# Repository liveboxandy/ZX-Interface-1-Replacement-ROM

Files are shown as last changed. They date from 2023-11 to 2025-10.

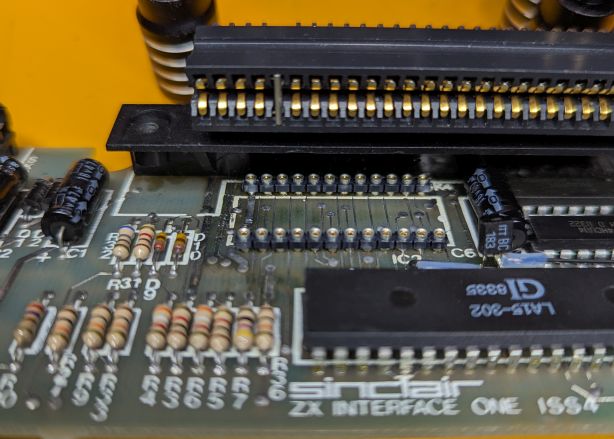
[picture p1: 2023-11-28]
Pictures/IF1 Sockets.jpg

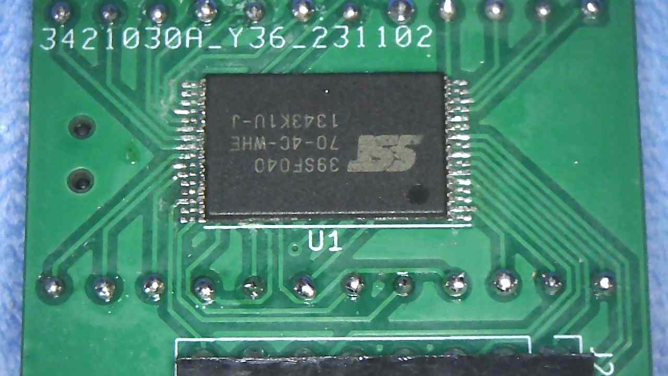
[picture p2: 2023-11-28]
Pictures/IF1 ROM SF040.jpg

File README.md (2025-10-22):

# ZX-Interface-1-Replacement-ROM
Replacement ROM for the ZX Interface 1

The original ROM for the ZX Interface 1 is a mask programmed device that is now obsolete. This work is based on an idea by Retroleum and others in using a flash device on a PCB in order to remap the pins to suit the original 24 pin device layout. When using the suggested Samtec pins there is just enough room in the Interface 1 to allow the use of Samtec sockets so the ROM can be removed if required. I have not found any other pins that are short enough to allow the use of a socket in the Interface 1. 

This PCB will support SST39SF010, SST39SF020 and SST39SF040 devices and will allow up to a maximum of 32 different ROM images to be used.

The orignal ROM is an 8K device but if address A13 is taken from the ROM and connected to A13 on the expansion BUS then the 16K ROM image by Ian Collier can be used. See picture for location of address A13 on the edge connector of the ZX Interface 1.

This has been updated to Kicad 9 and requires an adaptor board to remap the pins when programming.

The adapter board is available under ZX-Interface-1-Replacement-ROM-Programming-Adapter.

Comments - Good Bad or indifferent on https://www.facebook.com/groups/zxspa/

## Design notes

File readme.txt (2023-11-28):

Address Lines Avalable

Addr Hex  Dec  Max
A18 40000 256K 512K SST39SF040 Pulled Hi in Operation
A17 20000 128K 256K SST39SF020 Pulled Hi in Operation
A16 10000  64K 128K SST39SF010 Switched Hi/Lo by switch on my board.Pulled Lo by short to Ground on Retroleum.
A15  8000  32K  64K Switched Hi/Lo by switch on Retroleum.
A14  4000  16K  32K Pulled Hi in Operation
A13  2000   8K  16K Pulled Hi in Operation. Allows 16K Operation with wire add.
A12  1000   4K   8K
A11   800   2K   4K
A10   400   1K   2K 
A9    200  512   1K
A8    100  256  512
A7     80  128  256
6      40   64  128
5      20   32   64
4      10   16   32
3       8    8   16
2       4    4    8
1       2    2    4
0       1    1    2

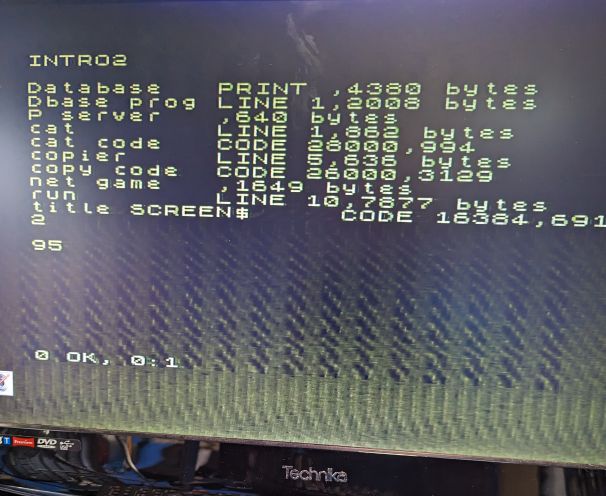
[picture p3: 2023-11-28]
Pictures/IMC ROM CAT.jpg

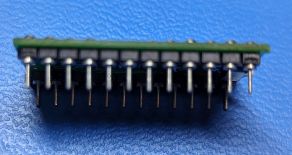
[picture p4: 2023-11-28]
Pictures/New ROM Pins.jpg

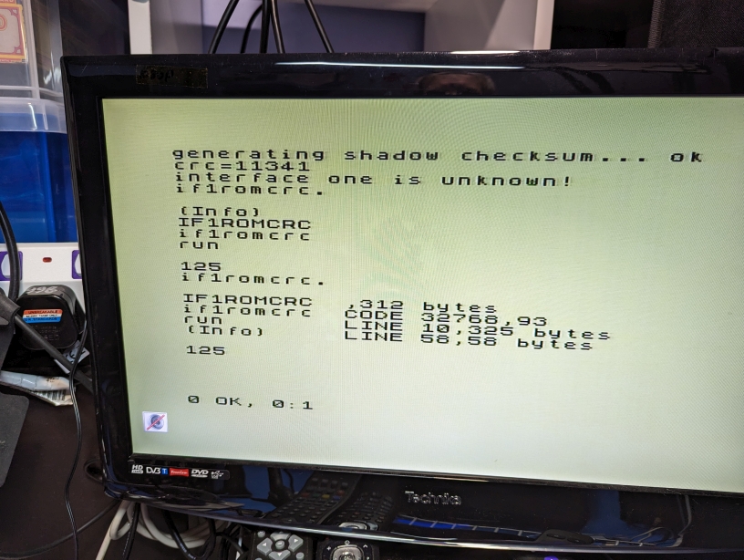
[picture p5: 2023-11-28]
Pictures/IMC Checksum & CAT.jpg

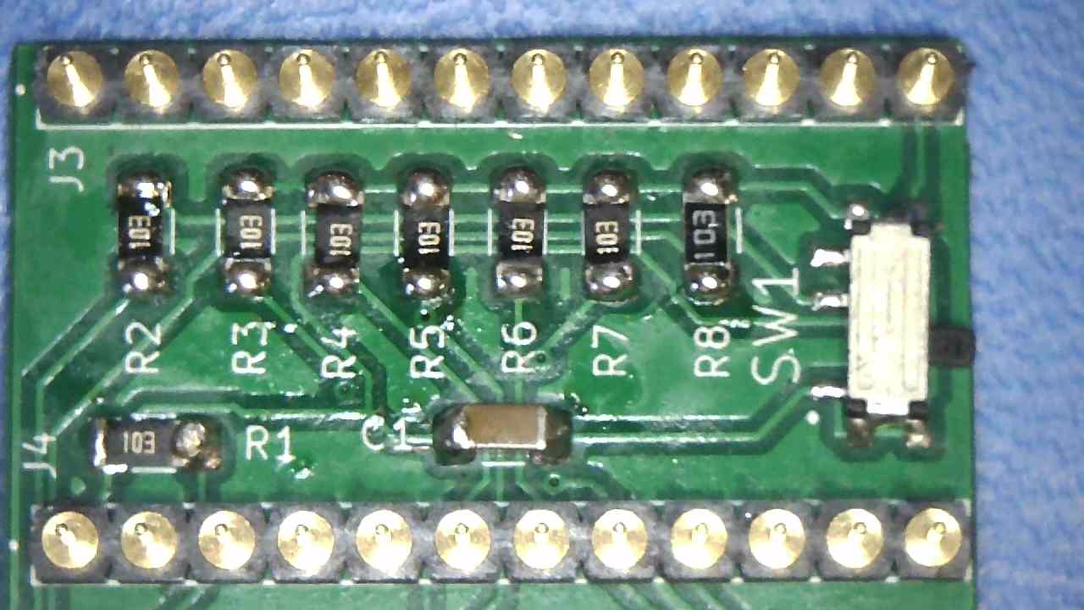
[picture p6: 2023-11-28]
Pictures/ROM Bottom Side.jpg

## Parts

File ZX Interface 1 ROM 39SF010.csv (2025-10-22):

Reference | Qty | Value | DNP | Exclude from BOM | Exclude from Board | Footprint | Datasheet
C1 | 1 | 100nF |  |  |  | Mod:C_1206_3216Metric_Pad1.33x1.80mm_HandSolder | ~
J1 | 1 | Conn_01x09_Pin |  |  |  | Switch:PinSocket_1x09_P2.54mm_HorizontalR | ~
J3,J4 | 2 | BBL-112-G-E |  |  |  | Mod:Pin-Pin Header 2.54mm Round Samtec BBL-112-G-E
R1,R2,R3,R4,R5,R6,R7,R8 | 8 | 10K |  |  |  | Mod:R_1206_3216Metric_Pad1.30x1.75mm_HandSolder | ~
SW1 | 1 | SW_SPDT |  |  |  | Mod:SW_PCM12SMTR | PCM12SMTR
U1 | 1 | SST39SF040A TSOP |  |  |  | Mod:TSOP-I-32_12.4x8mm_P0.5mm

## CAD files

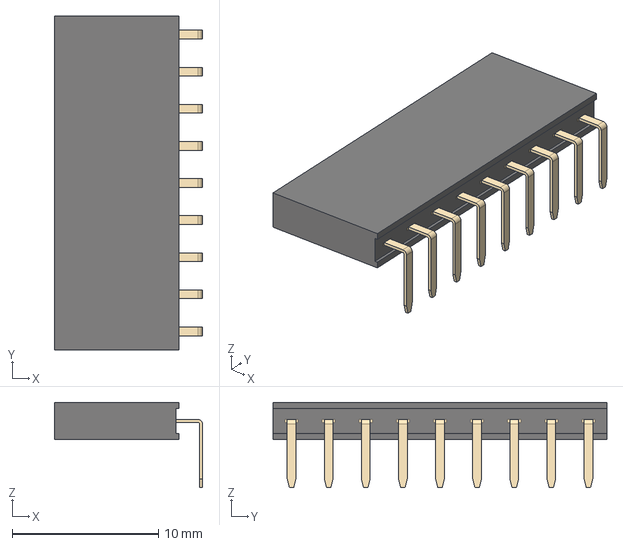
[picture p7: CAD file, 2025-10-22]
STEP/PinSocket_1x09_P2.54mm_Horizontal.step
10.1 x 22.9 x 5.84 mm

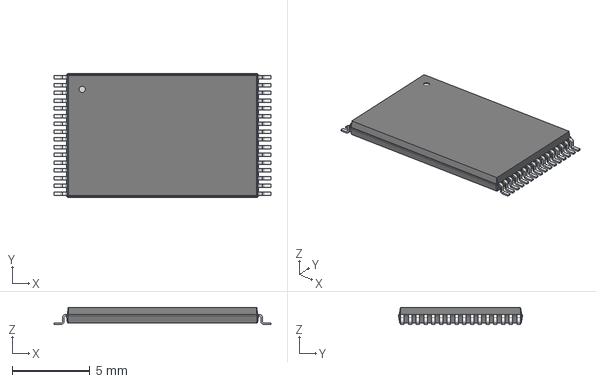
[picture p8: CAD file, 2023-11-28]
STEP/TSOP-I-32_12.4x8mm_P0.5mm.step
14.0 x 8.00 x 1.10 mm

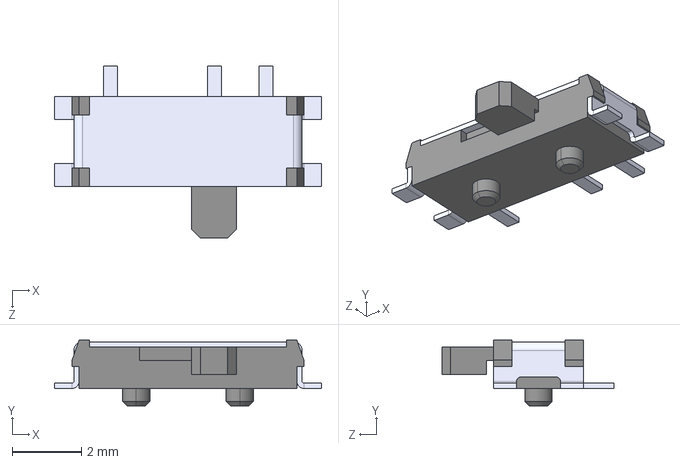
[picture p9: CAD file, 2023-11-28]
STEP/SW_PCM12SMTR.step
7.72 x 1.91 x 4.98 mm

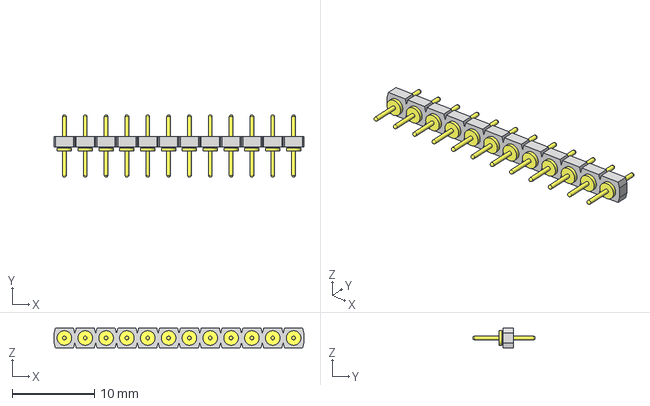
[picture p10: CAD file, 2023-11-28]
STEP/Pin-Pin Header 2.54mm Round Samtec BBL-112-G-E.stp
30.5 x 7.62 x 2.44 mm
BBL-112-G-E_pins x 12
BBL-112-G-E_socket

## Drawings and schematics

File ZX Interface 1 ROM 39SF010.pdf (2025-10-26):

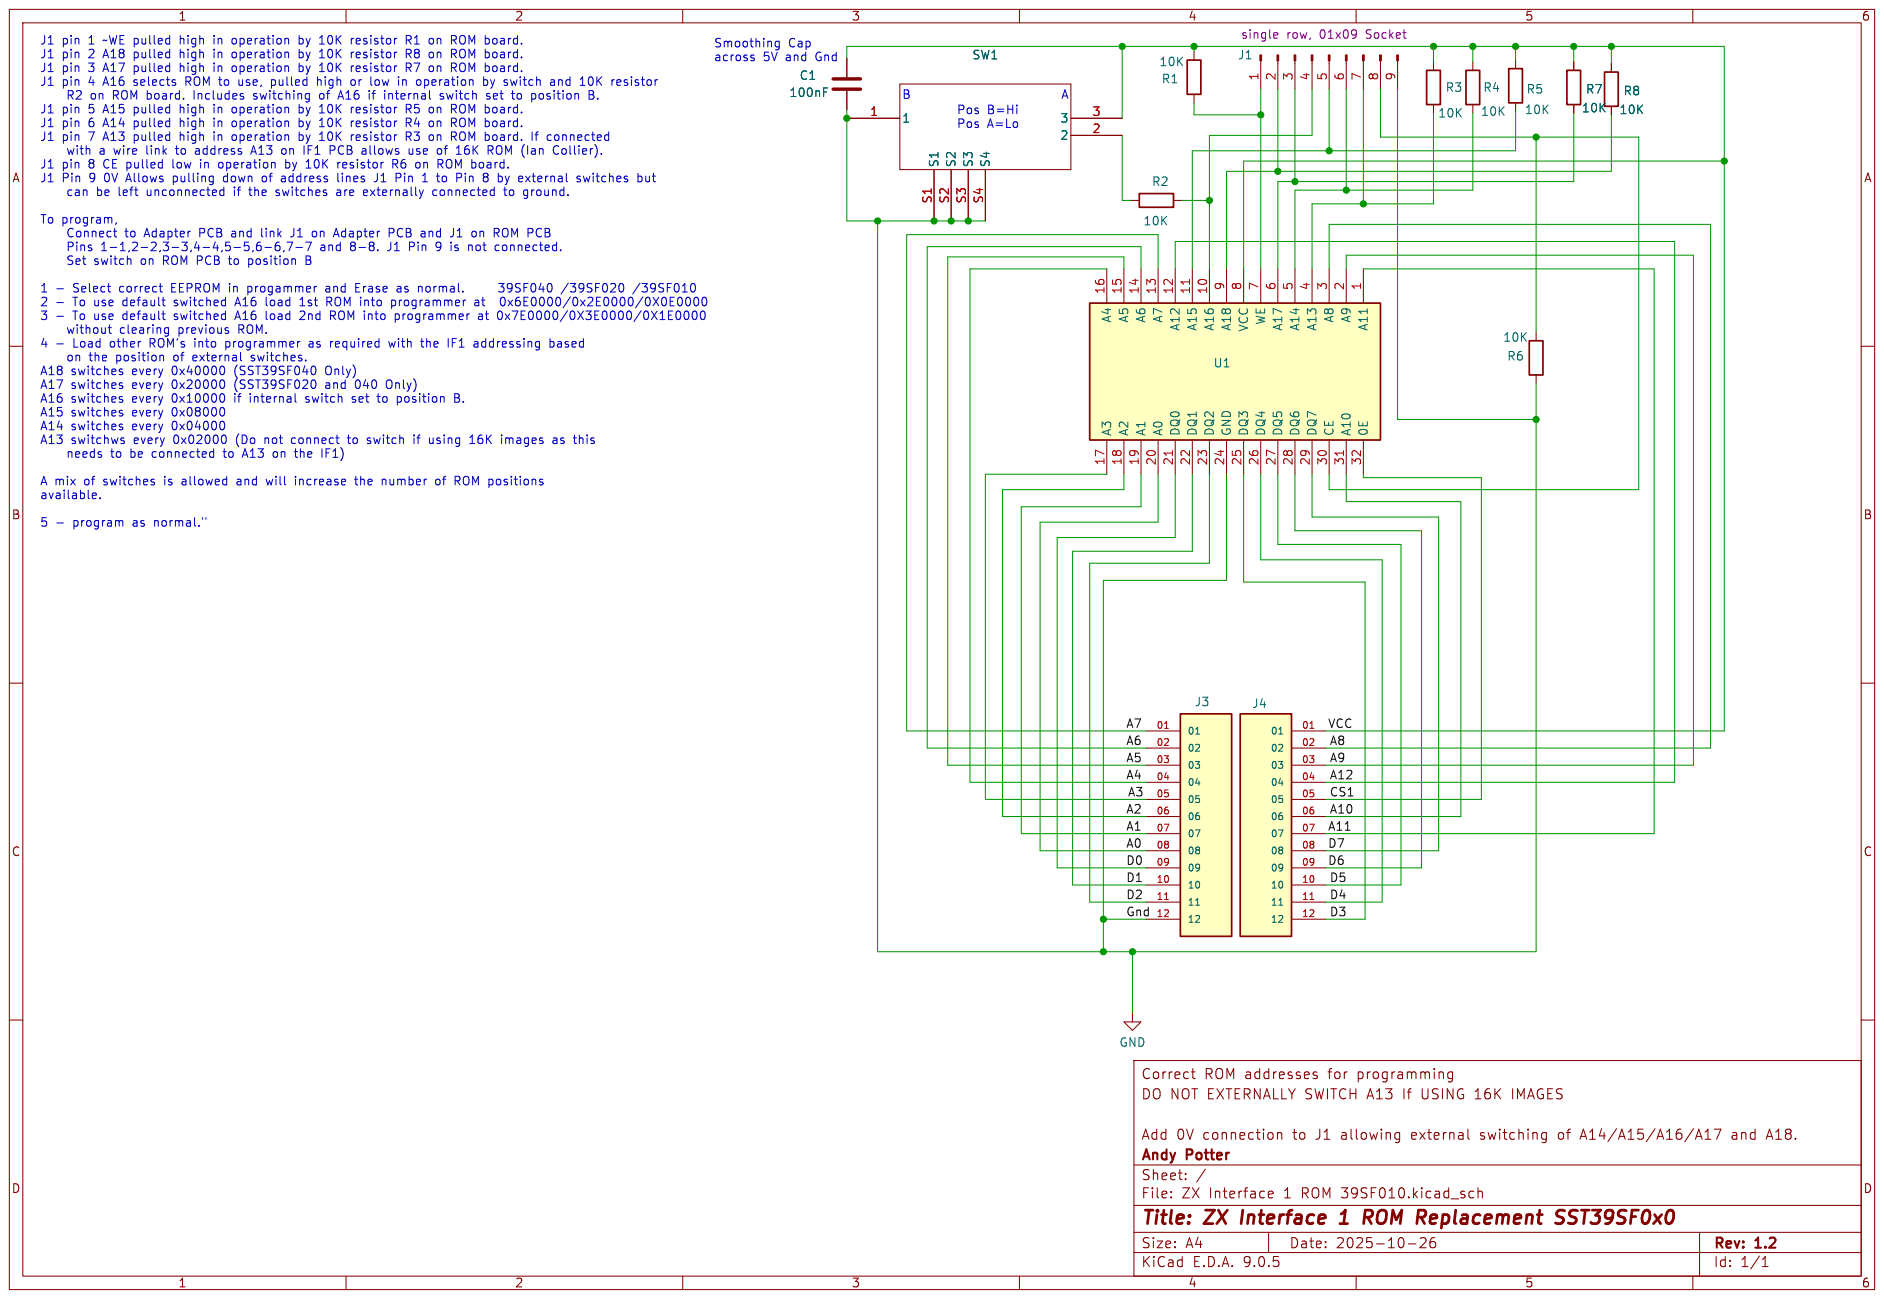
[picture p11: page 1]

Id: 1/1 Title: ZX Interface 1 ROM Replacement SST39SF0x0

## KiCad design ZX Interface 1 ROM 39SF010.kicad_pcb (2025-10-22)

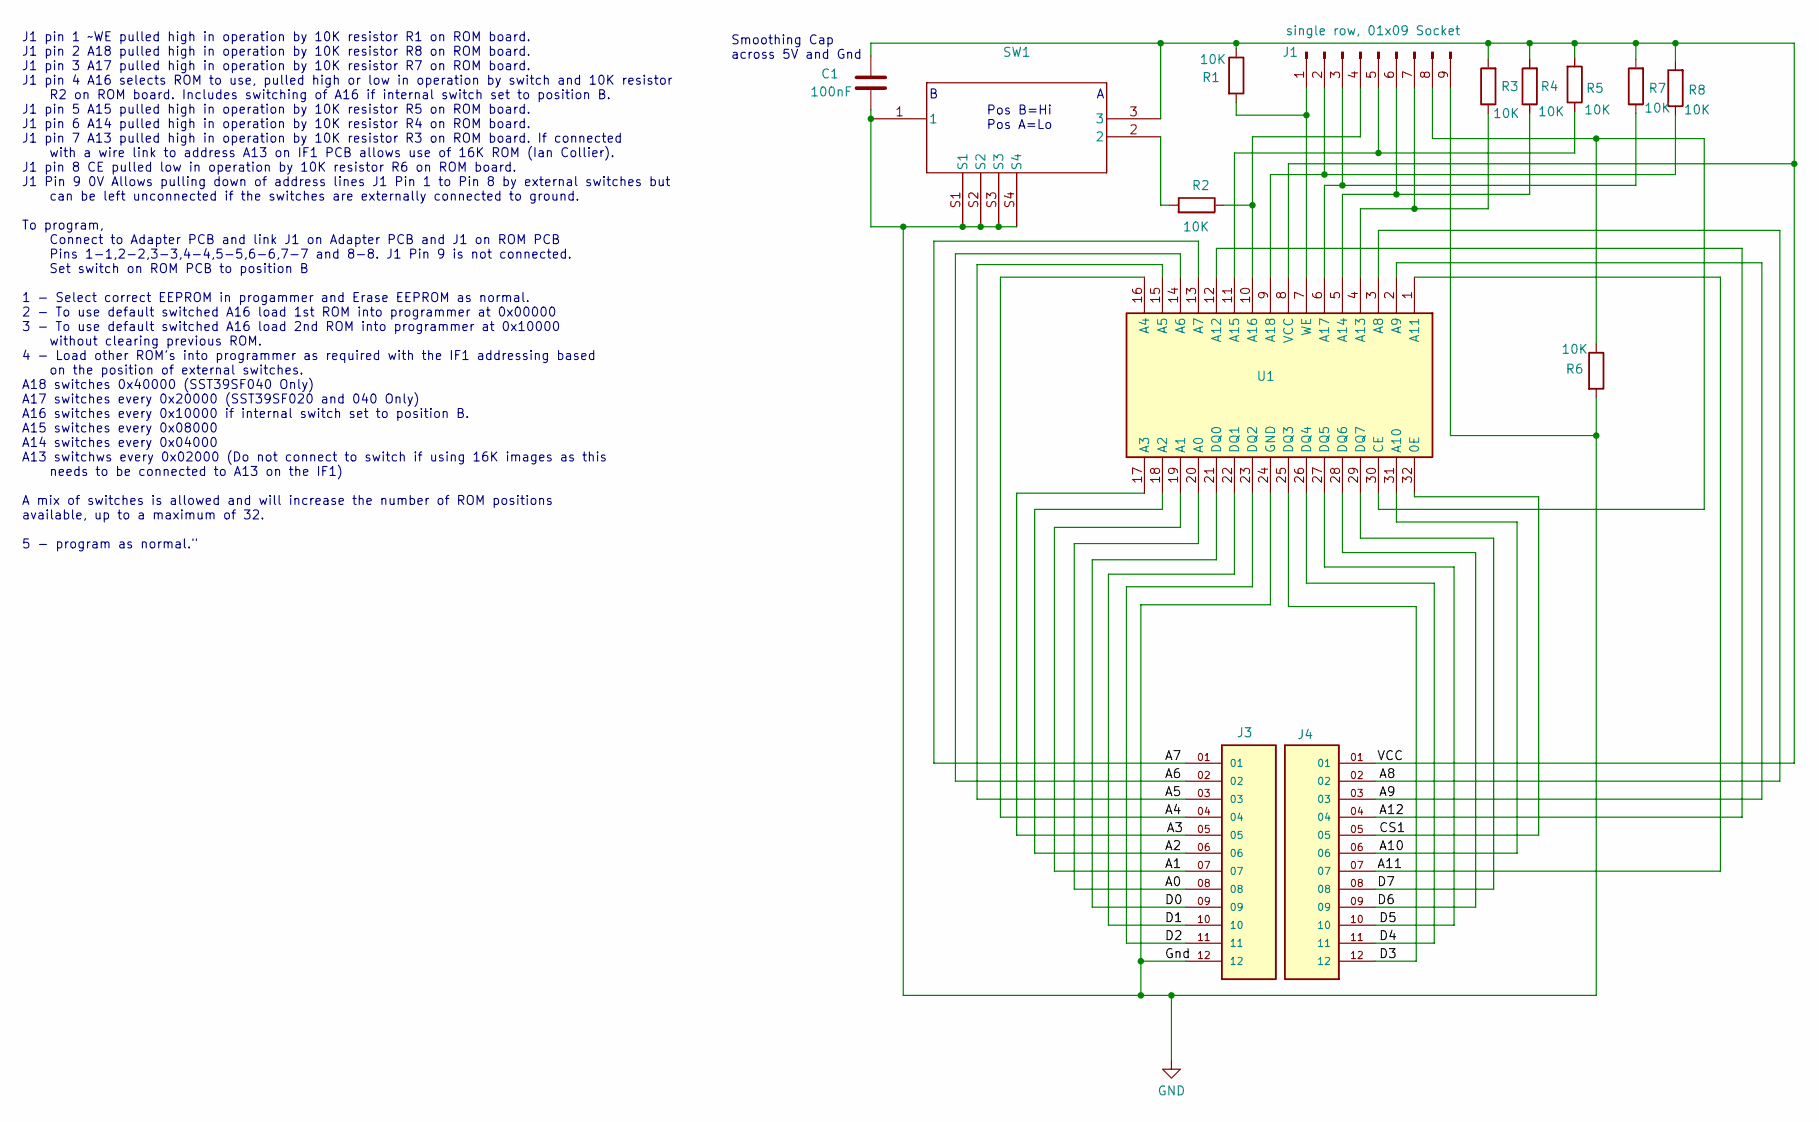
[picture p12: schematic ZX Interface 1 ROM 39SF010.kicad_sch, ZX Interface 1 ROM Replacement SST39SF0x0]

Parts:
C1: 100nF; C_1206_3216Metric_Pad1.33x1.80mm_HandSolder
J1: Conn_01x09_Pin; PinSocket_1x09_P2.54mm_HorizontalR
J3, J4: BBL-112-G-E; Pin-Pin Header 2.54mm Round Samtec BBL-112-G-E; PARTREV R
R1, R2, R3, R4, R5, R6, R7, R8: 10K; R_1206_3216Metric_Pad1.30x1.75mm_HandSolder
SW1: SW_SPDT; SW_PCM12SMTR
U1: SST39SF040A TSOP; TSOP-I-32_12.4x8mm_P0.5mm

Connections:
/A0: J3.08, U1.20 (A0)
/A1: J3.07, U1.19 (A1)
/A2: J3.06, U1.18 (A2)
/A3: J3.05, U1.17 (A3)
/A4: J3.04, U1.16 (A4)
/A5: J3.03, U1.15 (A5)
/A6: J3.02, U1.14 (A6)
/A7: J3.01, U1.13 (A7)
/A8: J4.02, U1.3 (A8)
/A9: J4.03, U1.2 (A9)
/A10: J4.06, U1.31 (A10)
/A11: J4.07, U1.1 (A11)
/A12: J4.04, U1.12 (A12)
/CS1: J4.05, U1.32 (0E)
/D0: J3.09, U1.21 (DQ0)
/D1: J3.10, U1.22 (DQ1)
/D2: J3.11, U1.23 (DQ2)
/D3: J4.12, U1.25 (DQ3)
/D4: J4.11, U1.26 (DQ4)
/D5: J4.10, U1.27 (DQ5)
/D6: J4.09, U1.28 (DQ6)
/D7: J4.08, U1.29 (DQ7)
/VCC: C1.1, J4.01, R1.1, R3.2, R4.2, R5.2, R7.2, R8.2, SW1.3, U1.8 (VCC)
GND: C1.2, J1.9, J3.12, R6.2, SW1.1, SW1.S1, SW1.S2, SW1.S3, SW1.S4, U1.24 (GND)
unnamed: J1.1, R1.2, U1.7 (WE)
unnamed: J1.2, R8.1, U1.9 (A18)
unnamed: J1.3, R7.1, U1.6 (A17)
unnamed: J1.4, R2.1, U1.10 (A16)
unnamed: J1.5, R5.1, U1.11 (A15)
unnamed: J1.6, R4.1, U1.5 (A14)
unnamed: J1.7, R3.1, U1.4 (A13)
unnamed: J1.8, R6.1, U1.30 (CE)
unnamed: R2.2, SW1.2

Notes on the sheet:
J1 pin 1 ~WE pulled high in operation by 10K resistor R1 on ROM board. J1 pin 2 A18 pulled high in operation by 10K resistor R8 on ROM board. J1 pin 3 A17 pulled high in operation by 10K resistor R7 on ROM board. J1 pin 4 A16 selects ROM to use, pulled high or low in operation by switch and 10K res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
Pos B=Hi Pos A=Lo
Smoothing Cap across 5V and Gnd

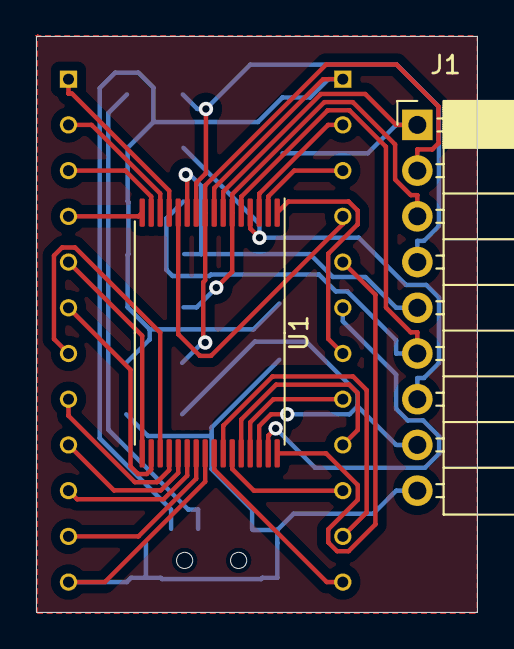
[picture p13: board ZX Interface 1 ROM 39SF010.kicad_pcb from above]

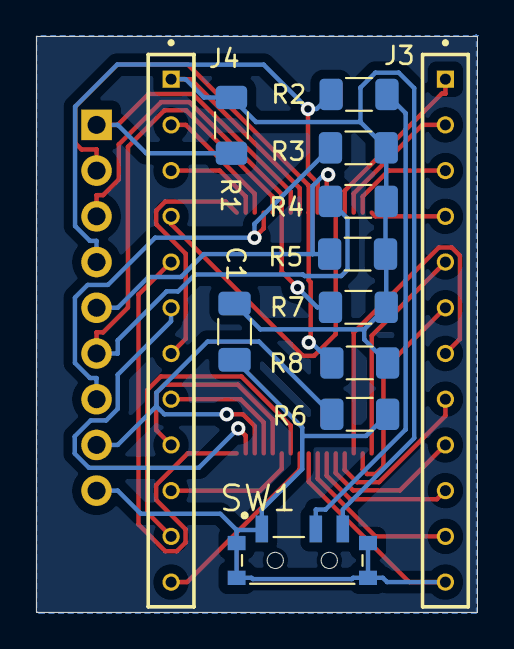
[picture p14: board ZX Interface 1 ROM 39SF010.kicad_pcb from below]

Board: 2 copper layers, 24.5 x 32.0 mm, 14 parts (12 on the bottom side), 33 nets.

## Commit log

2023-11-28 Update ZX Interface 1 ROM 39SF010.kicad_sch
    Correct max number of ROM's to 32 not 64.
    [ZX Interface 1 ROM 39SF010.kicad_sch]
2023-11-30 Updated to use Right Angle 9 pin Header
    [ZX Interface 1 ROM 39SF010-B_Cu.gbl, ZX Interface 1 ROM 39SF010-B_Mask.gbs, ZX Interface 1 ROM 39SF010-B_Paste.gbp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]
2025-10-22 Add files via upload
    Updated file to Kicad 9. Restructured folders. Added ibom (Interactive BOM)
    [Pin-Pin Header 2.54mm Round Samtec BBL-112-G-E.stp, PinSocket_1x09_P2.54mm_Horizontal.step, SW_PCM12SMTR.step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]
2025-10-26 Fix ROM Addresses for Programming
    Correct default addresses for programming and add table for address decoding
    [ZX Interface 1 ROM 39SF010.kicad_sch]
2025-10-26 Update PCB picture

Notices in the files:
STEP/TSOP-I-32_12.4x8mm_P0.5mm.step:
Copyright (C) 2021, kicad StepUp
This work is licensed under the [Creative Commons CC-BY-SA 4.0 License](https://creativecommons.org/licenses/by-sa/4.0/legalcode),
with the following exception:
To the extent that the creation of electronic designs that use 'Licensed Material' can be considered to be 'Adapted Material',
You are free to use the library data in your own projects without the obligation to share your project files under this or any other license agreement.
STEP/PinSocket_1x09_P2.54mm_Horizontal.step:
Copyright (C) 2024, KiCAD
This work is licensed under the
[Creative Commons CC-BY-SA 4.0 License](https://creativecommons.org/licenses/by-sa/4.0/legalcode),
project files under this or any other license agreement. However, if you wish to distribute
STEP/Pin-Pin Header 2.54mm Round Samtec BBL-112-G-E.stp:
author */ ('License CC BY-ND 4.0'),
